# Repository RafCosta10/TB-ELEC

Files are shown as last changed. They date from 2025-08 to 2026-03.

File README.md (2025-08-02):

# TB-ELEC

# Queen’s Hyperloop Electrical Subteam Repository

Welcome to the official repository for the Electrical Subteam of the Queen’s Hyperloop Tunnel & Boring group.

---

## 📋 About

This repository contains source code, firmware, design files, and documentation related to the electrical systems of our Hyperloop tunnel boring machine project. It is intended to support collaboration among current team members.

---

## 🚫 Usage Notice

This repository **does not have an open source license**.  
**All rights are reserved by the Queen’s Hyperloop Electrical Subteam.**  
The contents are provided for use *within the team only* and may not be copied, modified, or distributed outside the team without explicit permission.

---

## 📂 Repository Structure

- `/firmware` — Microcontroller code and scripts  
- `/tools` — Utilities and scripts supporting development  

---

## 🛠 Getting Started

- Please contact the Electrical Subteam Lead to request access or onboarding help.  
- Refer to the [Engineering Wiki](https://www.notion.so/235706a097758006bf46ff2deb52e041?v=235706a0977580078a06000c86afb2b6) for tutorials and guidelines.  
- Check the [Projects Dashboard](https://www.notion.so/235706a097758070890ec096f4407239?v=235706a097758027b426000c77134180) for current tasks and assignments.

---

## 🤝 Contribution

If you are a member of the Electrical Subteam and want to contribute:  
- Follow the team’s Git workflow guidelines (branching, commits, pull requests).  
- Coordinate with the project owner for reviews and testing.  

---

## 📞 Contact

Electrical Subteam Lead: [Rafael Costa] — [22xwyk@queensu.ca]  

---

Thanks for your interest and hard work! Let’s build something amazing together.

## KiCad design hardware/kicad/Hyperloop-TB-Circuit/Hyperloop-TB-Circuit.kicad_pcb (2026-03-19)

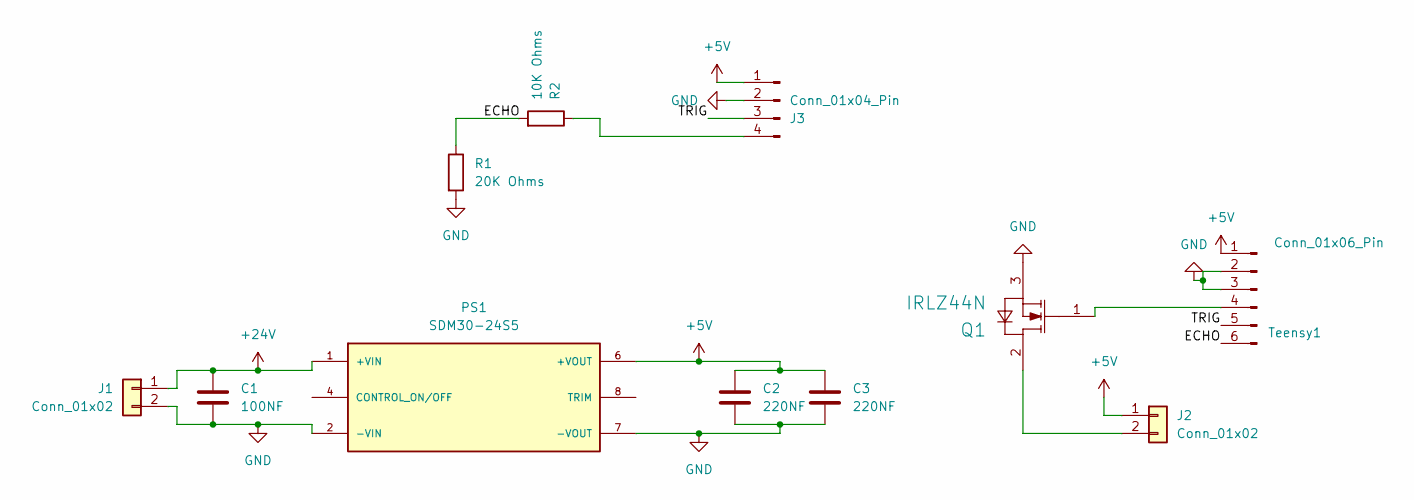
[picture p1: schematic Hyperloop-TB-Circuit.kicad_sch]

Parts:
C1: 100NF; C_Disc_D3.0mm_W1.6mm_P2.50mm
C2, C3: 220NF; C_Disc_D3.0mm_W1.6mm_P2.50mm
J1, J2: Conn_01x02; PinHeader_1x02_P1.00mm_Vertical
J3: Conn_01x04_Pin; Samtec_HPM-04-01-x-S_Straight_1x04_Pitch5.08mm
PS1: SDM30-24S5; CONV_SDM30-24S5; PARTREV 2018-01-12
Q1: IRLZ44N; IFX-PG-TO220-3-904-1
R1: 20K Ohms; R_Axial_DIN0204_L3.6mm_D1.6mm_P7.62mm_Horizontal
R2: 10K Ohms; R_Axial_DIN0204_L3.6mm_D1.6mm_P7.62mm_Horizontal
Teensy1: Conn_01x06_Pin; PinHeader_1x06_P1.00mm_Vertical

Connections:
+5V: C2.1, C3.1, J2.1, J3.1, PS1.6 (+VOUT), Teensy1.1
+24V: C1.1, J1.1, PS1.1 (+VIN)
/ECHO: R1.1, R2.2, Teensy1.6
/TRIG: J3.3, Teensy1.5
GND: C1.2, C2.2, C3.2, J1.2, J3.2, PS1.2 (-VIN), PS1.7 (-VOUT), Q1.3 (SOURCE), R1.2, Teensy1.2, Teensy1.3
unnamed: J2.2, Q1.2 (DRAIN)
unnamed: J3.4, R2.1
unnamed: Q1.1 (GATE), Teensy1.4

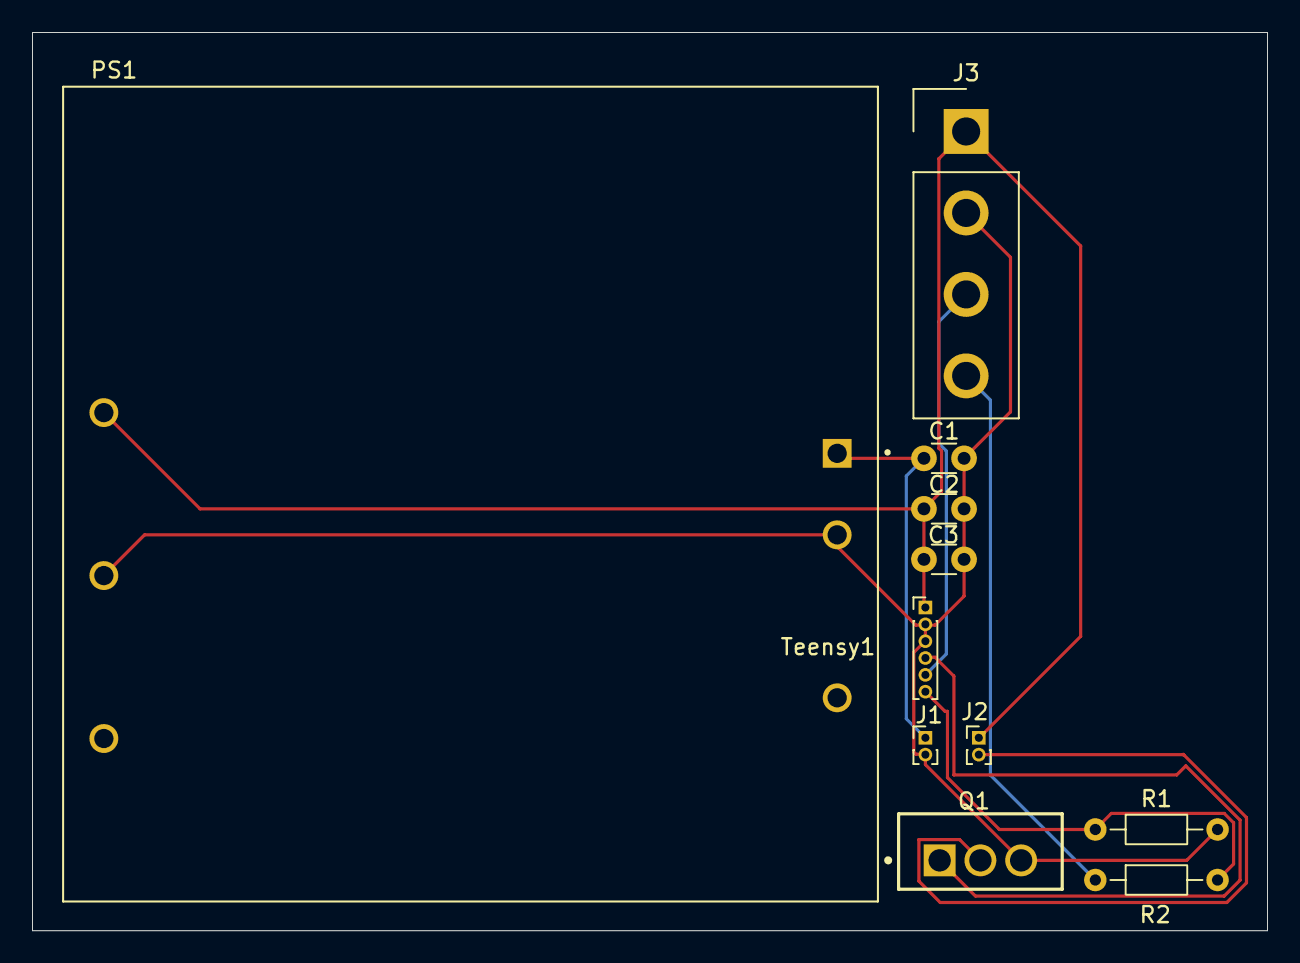
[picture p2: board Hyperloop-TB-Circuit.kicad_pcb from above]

Board: 2 copper layers, 77.0 x 56.0 mm, 11 parts (0 on the bottom side), 8 nets.

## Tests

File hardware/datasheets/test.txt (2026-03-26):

For Ultrasonic Sonar Distance Sensor: Need 3 5V VCC(5V) TRIG(5V) ECHO(5V) GND(GND) pins 1 GND pin
For DC/DC converter: Need 6 pins +VIN(24V) -VIN(GND) +VOUT(5V) -VOUT(GND) 
*DC/DC converter control notes* Open switch allows it to run closed tells it to stop from logic in the DC DC converter. So we need a switch
FOR switch: 4 connects to ground by itslef. 3 connects to gnd through a trace to 2 -VIN of D/DC converter . 1 connects to 4 control in the converter trhough a trace. (Ryan note: Each hole has its own thing then trace connects the holes)
For MOSSFET: VDSS Drain Gate source. Put voltage through gate then it contorls where current goes. Gate threshold voltage is 1V so thats difference between Gate and Source.
*Important note for Olivia* We need resisotr to make VGS = 1.5V
Flyback diode: Prevent current
Timer --> Sends signal to raspberry pi so when the timer stops the pi stops working

Next time: We need to figure out where diodes go and what the timer

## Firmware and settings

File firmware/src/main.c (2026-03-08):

#define _POSIX_C_SOURCE 200809L

#include <stdio.h>
#include <stdbool.h>
#include <stdlib.h>
#include <unistd.h>
#include <string.h>
#include <time.h>
#ifdef _WIN32
#include <conio.h>
#include <windows.h>
#else
#include <termios.h>
#include <fcntl.h>
#include <errno.h>
#include <arpa/inet.h>
#include <sys/socket.h>
#include <netinet/in.h>
#endif

#define TELEMETRY_PORT 5555

// 1. DEFINITIONS
typedef enum {
    IDLE,       // System idle, waiting to be armed
    ARMED,      // Safety loop closed, ready to start
    RUNNING,    // Motor is turning, simulated mining
    FAULT,      // Error state (E-Stop, Over-temp, etc.)
    SHUTDOWN    // Safe power down
} State;

// A struct to hold our fake data
typedef struct {
    float auger_rpm;
    float target_rpm;  // Target RPM for smooth transitions
    float temperature;
    float chainage; // Distance drilled
    float voltage;
    float current;
    float load_factor; // Simulates material hardness (1.0 = normal, >1.0 = tough)
    bool e_stop_pressed;
} SystemData;

// Global state variable
State current_state = IDLE;
int loop_counter = 0; // For simulating periodic load changes

// Function Prototypes
const char* getStateName(State s);
const char* getStateToken(State s);
void print_telemetry(SystemData *data);
void update_telemetry(SystemData *data);
void print_commands(void);
bool arm(void);
bool disarm(void);
void fault(void);
bool reset_fault(SystemData *data);
bool release_estop(SystemData *data);
int kbhit_check(void);
char getch_char(void);
void handle_command(char command, SystemData *data);

#ifndef _WIN32
bool telemetry_server_init(void);
void telemetry_server_close(void);
void telemetry_try_accept_client(void);
void telemetry_poll_client_commands(SystemData *data);
void telemetry_send_json(SystemData *data);
#endif

#ifndef _WIN32
int telemetry_server_fd = -1;
int telemetry_client_fd = -1;
#endif

// ==============================================
// STATE TRANSITION FUNCTIONS
// ==============================================

// Transition to ARMED state
bool arm(void) {
    if (current_state == IDLE) {
        printf(">> System Checks Passed. ARMING...\n");
        current_state = ARMED;
        return true;
    }
    printf(">> Cannot ARM from current state: %s\n", getStateName(current_state));
    return false;
}

// Transition to IDLE state
bool disarm(void) {
    if (current_state == ARMED || current_state == RUNNING) {
        printf(">> Stopping Motor... DISARMING.\n");
        current_state = IDLE;
        return true;
    }
    printf(">> Cannot DISARM from current state: %s\n", getStateName(current_state));
    return false;
}

// Transition to FAULT state
void fault(void) {
    printf(">> E-STOP TRIGGERED! Entering FAULT state.\n");
    current_state = FAULT;
}

// Reset from FAULT state
bool reset_fault(SystemData *data) {
    if (current_state == FAULT) {
        if (data->e_stop_pressed) {
            printf(">> Cannot reset: E-Stop still pressed. Release E-Stop first.\n");
            return false;
        }
        if (data->temperature > 60.0) {
            printf(">> Cannot reset: Temperature still too high (%.1f C). Wait for cooling.\n", data->temperature);
            return false;
        }
        printf(">> Fault Cleared. Returning to IDLE.\n");
        current_state = IDLE;
        return true;
    }
    printf(">> System is not in FAULT state.\n");
    return false;
}

// Release E-Stop button
bool release_estop(SystemData *data) {
    if (data->e_stop_pressed) {
        printf(">> E-Stop Released.\n");
        data->e_stop_pressed = false;
        return true;
    }
    printf(">> E-Stop is not pressed.\n");
    return false;
}

// ==============================================
// TELEMETRY GENERATION
// ==============================================

// Update telemetry based on current state
void update_telemetry(SystemData *data) {
    loop_counter++;
    
    switch (current_state) {
        case IDLE:
            // Low current, stable voltage, cooling down
            data->auger_rpm = 0;
            data->target_rpm = 0;
            data->voltage = 24.0;
            data->current = 0.5; // Standby current
            data->load_factor = 1.0;
            // Passive cooling toward ambient (25C)
            float idle_cooling = (data->temperature - 25.0) * 0.12; // Faster cooling when idle
            data->temperature -= idle_cooling;
            if (data->temperature < 25.0) data->temperature = 25.0;
            break;

        case ARMED:
            // Similar to IDLE but ready to start
            data->auger_rpm = 0;
            data->target_rpm = 0;
            data->voltage = 24.0;
            data->current = 0.8; // Slightly higher, system ready
            data->load_factor = 1.0;
            // Slower cooling when armed (systems energized)
            float armed_cooling = (data->temperature - 25.0) * 0.10;
            data->temperature -= armed_cooling;
            if (data->temperature < 25.0) data->temperature = 25.0;
            break;

        case RUNNING:
            // Simulate hitting tough material periodically
            if (loop_counter % 50 == 0) {
                // Random load spike every ~5 seconds
                data->load_factor = 1.0 + ((float)(rand() % 60) / 100.0); // 1.0 to 1.6x
            } else {
                // Gradually return to normal
                if (data->load_factor > 1.0) {
                    data->load_factor -= 0.02;
                    if (data->load_factor < 1.0) data->load_factor = 1.0;
                }
            }
            
            // Smooth RPM transitions (ramp up/down)
            if (data->auger_rpm < data->target_rpm) {
                data->auger_rpm += 25.0; // Ramp up 25 RPM per cycle
                if (data->auger_rpm > data->target_rpm) data->auger_rpm = data->target_rpm;
            } else if (data->auger_rpm > data->target_rpm) {
                data->auger_rpm -= 30.0; // Ramp down 30 RPM per cycle
                if (data->auger_rpm < data->target_rpm) data->auger_rpm = data->target_rpm;
            }
            
            // Current proportional to RPM and load
            float base_current = (data->auger_rpm / 1500.0) * 15.0; // 15A at max RPM
            float noise = ((float)(rand() % 20) / 10.0); // 0-2A noise
            data->current = (base_current + 3.0) * data->load_factor + noise;
            
            // Voltage drop under load
            data->voltage = 24.0 - (data->current / 100.0 * 2.0); // Drop with current
            
            // Temperature dynamics: heat generation vs cooling
            // Heat generated is proportional to current (power dissipation)
            float heat_generated = data->current * 0.15; // Heating rate from current
            // Heat dissipated is proportional to temp difference from ambient (25C)
            float heat_dissipated = (data->temperature - 25.0) * 0.08; // Cooling rate
            // Net temperature change
            float temp_change = heat_generated - heat_dissipated;
            data->temperature += temp_change;
            
            // Clamp temperature to reasonable range
            if (data->temperature < 25.0) data->temperature = 25.0;
            if (data->temperature > 120.0) data->temperature = 120.0;
            
            // Movement proportional to RPM
            data->chainage += (data->auger_rpm / 1500.0) * 0.1;
            break;

        case FAULT:
            // Motor stops, current falls exponentially
            data->auger_rpm = 0;
            data->target_rpm = 0;
            data->voltage = 23.8;
            
            // Current decays exponentially toward zero
            if (data->current > 0.5) {
                data->current *= 0.85; // Exponential decay
            } else {
                data->current = 0.5; // Settles to standby
            }
            
            // Temperature stays frozen
            // Cooling only if e_stop released
            if (!data->e_stop_pressed && data->temperature > 25.0) {
                float fault_cooling = (data->temperature - 25.0) * 0.05; // Slow cooling in fault
                data->temperature -= fault_cooling;
                if (data->temperature < 25.0) data->temperature = 25.0;
            }
            break;

        case SHUTDOWN:
            // All systems off
            data->auger_rpm = 0;
            data->target_rpm = 0;
            data->voltage = 0.0;
            data->current = 0.0;
            data->load_factor = 1.0;
            break;

        default:
            break;
    }
}

// ==============================================
// HELPER FUNCTIONS
// ==============================================

// Helper to convert Enum to String for printing
const char* getStateName(State s) {
    switch(s) {
        case IDLE: return "IDLE";
        case ARMED: return "ARMED (READY)";
        case RUNNING: return "RUNNING";
        case FAULT: return "FAULT / E-STOP";
        case SHUTDOWN: return "SHUTDOWN";
        default: return "UNKNOWN";
    }
}

const char* getStateToken(State s) {
    switch(s) {
        case IDLE: return "IDLE";
        case ARMED: return "ARMED";
        case RUNNING: return "RUNNING";
        case FAULT: return "FAULT";
        case SHUTDOWN: return "SHUTDOWN";
        default: return "UNKNOWN";
    }
}

// Helper to display telemetry
void print_telemetry(SystemData *data) {
    // Move cursor to home position (0,0) without clearing - eliminates flicker
    printf("\033[H");
    
    printf("\n========================================\n");
    printf("   TBM SIMULATOR - LIVE VIEW\n");
    printf("========================================\n");
    printf("STATE:       %-20s\n", getStateName(current_state));
    printf("----------------------------------------\n");
    printf("Voltage:     %-20.2f V\n", data->voltage);
    printf("Current:     %-20.2f A\n", data->current);
    printf("Temperature: %-20.1f C\n", data->temperature);
    printf("RPM:         %.0f / %.0f (target)     \n", data->auger_rpm, data->target_rpm);
    printf("Load Factor: %.2fx %-20s\n", data->load_factor, 
           data->load_factor > 1.2 ? "[TOUGH MATERIAL!]" : "");
    printf("Chainage:    %-20.1f m\n", data->chainage);
    printf("E-Stop:      %-20s\n", data->e_stop_pressed ? "PRESSED" : "Released");
    printf("========================================\n");
}

// Helper to display available commands
void print_commands(void) {
    printf("\nAVAILABLE COMMANDS:                     \n");
    printf("  [a] Arm System     [d] Disarm System  \n");
    printf("  [s] Start Running  [e] Press E-STOP   \n");
    printf("  [u] Release E-STOP [r] Reset Fault    \n");
    printf("  [+] Increase RPM   [-] Decrease RPM   \n");
    printf("  [t] Simulate Overheat                 \n");
    printf("  [x] Shutdown & Exit                   \n");
    printf("========================================\n");
}

// Non-blocking keyboard input check
int kbhit_check(void) {
    #ifdef _WIN32
    return _kbhit();
    #else
    struct termios oldt, newt;
    int ch;
    int oldf;
    
    tcgetattr(STDIN_FILENO, &oldt);
    newt = oldt;
    newt.c_lflag &= ~(ICANON | ECHO);
    tcsetattr(STDIN_FILENO, TCSANOW, &newt);
    oldf = fcntl(STDIN_FILENO, F_GETFL, 0);
    fcntl(STDIN_FILENO, F_SETFL, oldf | O_NONBLOCK);
    
    ch = getchar();
    
    tcsetattr(STDIN_FILENO, TCSANOW, &oldt);
    fcntl(STDIN_FILENO, F_SETFL, oldf);
    
    if(ch != EOF) {
        ungetc(ch, stdin);
        return 1;
    }
    return 0;
    #endif
}

// Get character without blocking
char getch_char(void) {
    #ifdef _WIN32
    return _getch();
    #else
    return getchar();
    #endif
}

void handle_command(char command, SystemData *data) {
    switch (command) {
        case 'a':
        case 'A':
            arm();
            break;

        case 'd':
        case 'D':
            disarm();
            break;

        case 's':
        case 'S':
            if (current_state == ARMED) {
                printf(">> Contactor Closed. DRILLING STARTED.\n");
                current_state = RUNNING;
            } else {
                printf(">> Must be ARMED before starting.\n");
            }
            break;

        case 'e':
        case 'E':
            data->e_stop_pressed = true;
            fault();
            break;

        case 'u':
        case 'U':
            release_estop(data);
            break;

        case 'r':
        case 'R':
            reset_fault(data);
            break;

        case '+':
        case '=':
            if (current_state == RUNNING) {
                data->target_rpm += 100;
                if (data->target_rpm > 2000) data->target_rpm = 2000;
                printf(">> Increasing target RPM to %.0f\n", data->target_rpm);
            } else {
                printf(">> Must be RUNNING to adjust RPM\n");
            }
            break;

        case '-':
        case '_':
            if (current_state == RUNNING) {
                data->target_rpm -= 100;
                if (data->target_rpm < 500) data->target_rpm = 500;
                printf(">> Decreasing target RPM to %.0f\n", data->target_rpm);
            } else {
                printf(">> Must be RUNNING to adjust RPM\n");
            }
            break;

        case 't':
        case 'T':
            printf(">> Simulating overheat...\n");
            data->temperature = 90.0;
            break;

        case 'x':
        case 'X':
            printf(">> Shutting down...\n");
            current_state = SHUTDOWN;
            break;

        default:
            break;
    }
}

#ifndef _WIN32
bool telemetry_server_init(void) {
    struct sockaddr_in addr;
    int opt = 1;

    telemetry_server_fd = socket(AF_INET, SOCK_STREAM, 0);
    if (telemetry_server_fd < 0) {
        perror("socket");
        return false;
    }

    if (setsockopt(telemetry_server_fd, SOL_SOCKET, SO_REUSEADDR, &opt, sizeof(opt)) < 0) {
        perror("setsockopt");
        close(telemetry_server_fd);
        telemetry_server_fd = -1;
        return false;
    }

    memset(&addr, 0, sizeof(addr));
    addr.sin_family = AF_INET;
    addr.sin_port = htons(TELEMETRY_PORT);
    addr.sin_addr.s_addr = htonl(INADDR_LOOPBACK);

    if (bind(telemetry_server_fd, (struct sockaddr*)&addr, sizeof(addr)) < 0) {
        perror("bind");
        close(telemetry_server_fd);
        telemetry_server_fd = -1;
        return false;
    }

    if (listen(telemetry_server_fd, 1) < 0) {
        perror("listen");
        close(telemetry_server_fd);
        telemetry_server_fd = -1;
        return false;
    }

    if (fcntl(telemetry_server_fd, F_SETFL, O_NONBLOCK) < 0) {
        perror("fcntl");
        close(telemetry_server_fd);
        telemetry_server_fd = -1;
        return false;
    }

    printf(">> Telemetry server listening on 127.0.0.1:%d\n", TELEMETRY_PORT);
    return true;
}

void telemetry_server_close(void) {
    if (telemetry_client_fd >= 0) {
        close(telemetry_client_fd);
        telemetry_client_fd = -1;
    }
    if (telemetry_server_fd >= 0) {
        close(telemetry_server_fd);
        telemetry_server_fd = -1;
    }
}

void telemetry_try_accept_client(void) {
    int client_fd;

    if (telemetry_server_fd < 0 || telemetry_client_fd >= 0) {
        return;
    }

    client_fd = accept(telemetry_server_fd, NULL, NULL);
    if (client_fd < 0) {
        return;
    }

    if (fcntl(client_fd, F_SETFL, O_NONBLOCK) < 0) {
        close(client_fd);
        return;
    }

    telemetry_client_fd = client_fd;
    printf(">> GUI connected on localhost socket.\n");
}

void telemetry_poll_client_commands(SystemData *data) {
    char buffer[64];
    ssize_t bytes_read;
    int i;

    if (telemetry_client_fd < 0) {
        return;
    }

    bytes_read = recv(telemetry_client_fd, buffer, sizeof(buffer), 0);
    if (bytes_read > 0) {
        for (i = 0; i < bytes_read; i++) {
            char c = buffer[i];
            if (c == '\n' || c == '\r') {
                continue;
            }
            handle_command(c, data);
        }
        return;
    }

    if (bytes_read == 0) {
        close(telemetry_client_fd);
        telemetry_client_fd = -1;
        printf(">> GUI disconnected.\n");
        return;
    }

    if (errno != EAGAIN && errno != EWOULDBLOCK) {
        close(telemetry_client_fd);
        telemetry_client_fd = -1;
        printf(">> GUI socket error, closing client connection.\n");
    }
}

void telemetry_send_json(SystemData *data) {
    char payload[320];
    int len;
    ssize_t sent;

    if (telemetry_client_fd < 0) {
        return;
    }

    len = snprintf(payload, sizeof(payload),
                   "{\"state\":\"%s\",\"voltage\":%.3f,\"current\":%.3f,\"temperature\":%.3f,\"auger_rpm\":%.2f,\"target_rpm\":%.2f,\"load_factor\":%.3f,\"chainage\":%.3f,\"e_stop_pressed\":%d}\n",
                   getStateToken(current_state),
                   data->voltage,
                   data->current,
                   data->temperature,
                   data->auger_rpm,
                   data->target_rpm,
                   data->load_factor,
                   data->chainage,
                   data->e_stop_pressed ? 1 : 0);

    sent = send(telemetry_client_fd, payload, (size_t)len, 0);
    if (sent < 0 && errno != EAGAIN && errno != EWOULDBLOCK) {
        close(telemetry_client_fd);
        telemetry_client_fd = -1;
        printf(">> Failed to send telemetry, client disconnected.\n");
    }
}
#endif

// ==============================================
// 2. MAIN LOOP (The "Brain")
// ==============================================
int main() {
    SystemData sensors = {0.0, 1500.0, 25.0, 0.0, 24.0, 0.5, 1.0, false}; // Initial values
    char command = 0;

    printf("--- TBM BRAIN SIMULATOR INITIALIZED ---\n");
    printf("Starting live display in 2 seconds...\n");
    #ifdef _WIN32
    Sleep(2000);
    #else
    sleep(2);
    #endif

    #ifndef _WIN32
    if (!telemetry_server_init()) {
        printf(">> Warning: telemetry socket unavailable, continuing without GUI stream.\n");
    }
    #endif
    
    // Clear screen once at startup
    #ifdef _WIN32
    system("cls");
    #else
    printf("\033[2J\033[H");
    #endif

    // The Infinite Loop (Simulating the Teensy)
    while (current_state != SHUTDOWN) {

        #ifndef _WIN32
        telemetry_try_accept_client();
        telemetry_poll_client_commands(&sensors);
        #endif
        
        // A. UPDATE TELEMETRY BASED ON STATE
        update_telemetry(&sensors);

        // B. CHECK SAFETY INTERLOCKS (Automatic Transitions)
        if (sensors.temperature > 80.0 && current_state != FAULT) {
            sensors.e_stop_pressed = true;
            fault();
        }

        // C. DISPLAY TELEMETRY AND COMMANDS
        print_telemetry(&sensors);
        print_commands();

        #ifndef _WIN32
        telemetry_send_json(&sensors);
        #endif

        // D. CHECK FOR USER INPUT (Non-blocking)
        if (kbhit_check()) {
            command = getch_char();

            // E. STATE MACHINE LOGIC (Using transition functions)
            handle_command(command, &sensors);
        }
        
        // F. Update rate (10 Hz = 100ms)
        #ifdef _WIN32
        Sleep(100);
        #else
        struct timespec ts = {0, 100000000};
        nanosleep(&ts, NULL);
        #endif
    }

    #ifndef _WIN32
    telemetry_server_close();
    #endif

    printf("\n--- SYSTEM SHUTDOWN COMPLETE ---\n");
    return 0;
}

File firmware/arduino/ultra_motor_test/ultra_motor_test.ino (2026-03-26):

/*
  Motor and Ultrasonic Sensor Test for Arduino

  Controls through Serial Monitor:
  - Send 's' to start motor
  - Send 'x' to stop motor
  - Send 'q' to print quit message (Arduino keeps running unless reset)
*/

const int MOTOR_PIN = 2;
const int ULTRASONIC_TRIG = 3;
const int ULTRASONIC_ECHO = 4;

bool motorRunning = false;

void setup() {
  Serial.begin(9600);

  pinMode(MOTOR_PIN, OUTPUT);
  digitalWrite(MOTOR_PIN, LOW);

  pinMode(ULTRASONIC_TRIG, OUTPUT);
  pinMode(ULTRASONIC_ECHO, INPUT);

  Serial.println("==================================================");
  Serial.println("Motor & Ultrasonic Sensor Test - Arduino");
  Serial.println("==================================================");
  Serial.println();
  Serial.println("Controls:");
  Serial.println("  's' - Start motor");
  Serial.println("  'x' - Stop motor");
  Serial.println("  'q' - Print quit message");
  Serial.println();

  delay(100); // sensor settle time
}

void startMotor() {
  digitalWrite(MOTOR_PIN, HIGH);
  motorRunning = true;
  Serial.println("Motor STARTED");
}

void stopMotor() {
  digitalWrite(MOTOR_PIN, LOW);
  motorRunning = false;
  Serial.println("Motor STOPPED");
}

const char* getMotorStatus() {
  return motorRunning ? "Running" : "Stopped";
}

float getDistanceCm() {
  // Ensure trigger is low
  digitalWrite(ULTRASONIC_TRIG, LOW);
  delayMicroseconds(2);

  // Send 10 us pulse
  digitalWrite(ULTRASONIC_TRIG, HIGH);
  delayMicroseconds(10);
  digitalWrite(ULTRASONIC_TRIG, LOW);

  // Read pulse width with timeout (100000 us = 100 ms)
  unsigned long duration = pulseIn(ULTRASONIC_ECHO, HIGH, 100000);

  // If timeout happened
  if (duration == 0) {
    return -1;
  }

  // Speed of sound: 0.0343 cm/us
  // Distance = (duration * speed) / 2
  float distance = (duration * 0.0343) / 2.0;

  return distance;
}

void loop() {
  // Check for serial input
  if (Serial.available() > 0) {
    char key = Serial.read();

    if (key == 's' || key == 'S') {
      startMotor();
    } 
    else if (key == 'x' || key == 'X') {
      stopMotor();
    } 
    else if (key == 'q' || key == 'Q') {
      Serial.println("Quit requested. Reset Arduino to fully stop.");
      stopMotor();
    }
  }

  // Read ultrasonic distance
  float distance = getDistanceCm();

  if (distance >= 0) {
    Serial.print("Distance: ");
    Serial.print(distance, 2);
    Serial.print(" cm | Motor: ");
    Serial.println(getMotorStatus());
  } else {
    Serial.print("Distance: TIMEOUT | Motor: ");
    Serial.println(getMotorStatus());
  }

  delay(100);
}

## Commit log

2026-02-01 Initialize main.c with state enumeration and function prototypes
2026-02-01 Add INVALID state and update function prototypes in main.c
2026-02-08 Fix variable declaration for current_state in main function and add VSCode settings for compiler path
    [main.c]
2026-02-18 Adding kicad files to the project
    [Hyperloop-TB-Circuit.kicad_pcb, Hyperloop-TB-Circuit.kicad_sch]
2026-02-19 Adding Kicad project libraries
    [Hyperloop-TB-Circuit.kicad_pcb]
2026-02-19 Kicad cicuit diagram
    [Hyperloop-TB-Circuit.kicad_sch]
2026-02-20 Finishing kicad drawing
    [Hyperloop-TB-Circuit.kicad_sch]
2026-03-01 Adding footprint lib
2026-03-01 Pushing file for Jacob
    [Hyperloop-TB-Circuit.kicad_sch]
2026-03-08 Mosfet Symbol and Footprint
    [IFX-PG-TO220-3-904-1.PcbLib, IRLZ44N.SchLib]
2026-03-08 Mosfet added to library
2026-03-08 Mosfet footprint to kicad library
2026-03-08 Connected Resistor Footprints to schematic
    [Hyperloop-TB-Circuit.kicad_sch]
2026-03-08 Add GUI functionality and telemetry display for system monitoring
    - Introduced a new GUI module to visualize system states including voltage, current, temperature, and RPM.
    - Implemented buttons for controlling system states such as arm, disarm, start, and emergency stop.
    - Enhanced telemetry features to provide real-time updates on system parameters.
    - Added error handling for socket connections and JSON parsing.
    - Improved user interface responsiveness and aesthetics with custom styles.
    [main.c]
2026-03-08 Connected all the parts to a footprint schematic
    [Hyperloop-TB-Circuit.kicad_sch]
2026-03-08 HC-SR04 Ultrasonic Sonar Distance Sensor footprint (lit just 4 pins)
2026-03-08 Ultrasonic footprint (4pins for jumper wires)
2026-03-10 Reposition components in KiCad schematic
    Update Hyperloop-TB-Circuit.kicad_sch with numerous coordinate adjustments (junctions, wires, labels and symbol positions) to tidy up the schematic layout. Also update the Teensy 4.1 example schemati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
    [Hyperloop-TB-Circuit.kicad_sch, Teensy 4.1 Example.kicad_sch]
2026-03-15 adding motor
2026-03-15 connected footprints
    [Hyperloop-TB-Circuit.kicad_sch]
2026-03-15 updated schematic and pcb
    [Hyperloop-TB-Circuit.kicad_pcb, Hyperloop-TB-Circuit.kicad_sch]
2026-03-19 new pcb
    [Hyperloop-TB-Circuit.kicad_pcb]
2026-03-26 Update motor and ultrasonic sensor pin configuration in ultra_motor_test.ino
2026-03-26 Add ultra_motor_test.ino for motor and ultrasonic sensor control
